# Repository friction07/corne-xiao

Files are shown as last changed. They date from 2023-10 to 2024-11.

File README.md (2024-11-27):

# corne-xiao

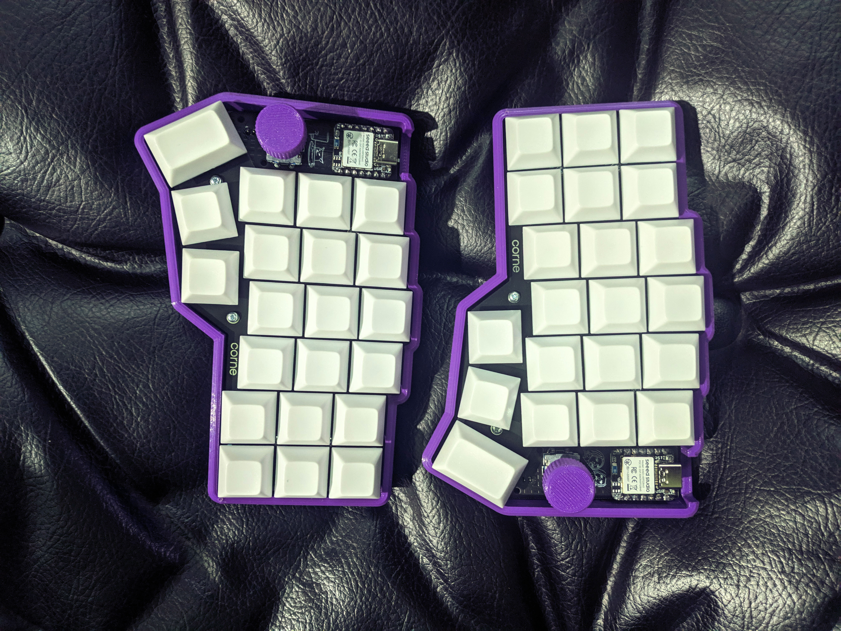
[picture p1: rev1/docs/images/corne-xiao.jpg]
corne-xiao


This is a modified version of the corne keyboard by foostan. It is wireless and uses zmk firmware.
- uses [Seeed Studio XIAO nRF52840](https://www.seeedstudio.com/Seeed-XIAO-BLE-nRF52840-p-5201.html) 
- supports rotary encoder on each half
- supports nice!view
- has a power button and JST header for the battery
- pcb has teardrops

*You can place either an oled or an encoder due to limited space*

***

### rev2
Reversible and breakable(5/6 column) pcb based on corne v2 (north facing).

### rev1 
Non reversible pcb based on corne v3 (south facing). 

***

### Refrences
Thanks to all these project which have been a huge help to me
 
- foostan's [crkbd](https://github.com/foostan/crkbd) 
- GEIST's [KLOR](https://github.com/GEIGEIGEIST/KLOR) and [TOTEM](https://github.com/GEIGEIGEIST/TOTEM)
- Jon Muller's [corne-choc-xiao](https://github.com/JonMuller/gerbers/tree/main/corne-choc-xiao)

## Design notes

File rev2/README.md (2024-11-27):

# CORNE-XIAO

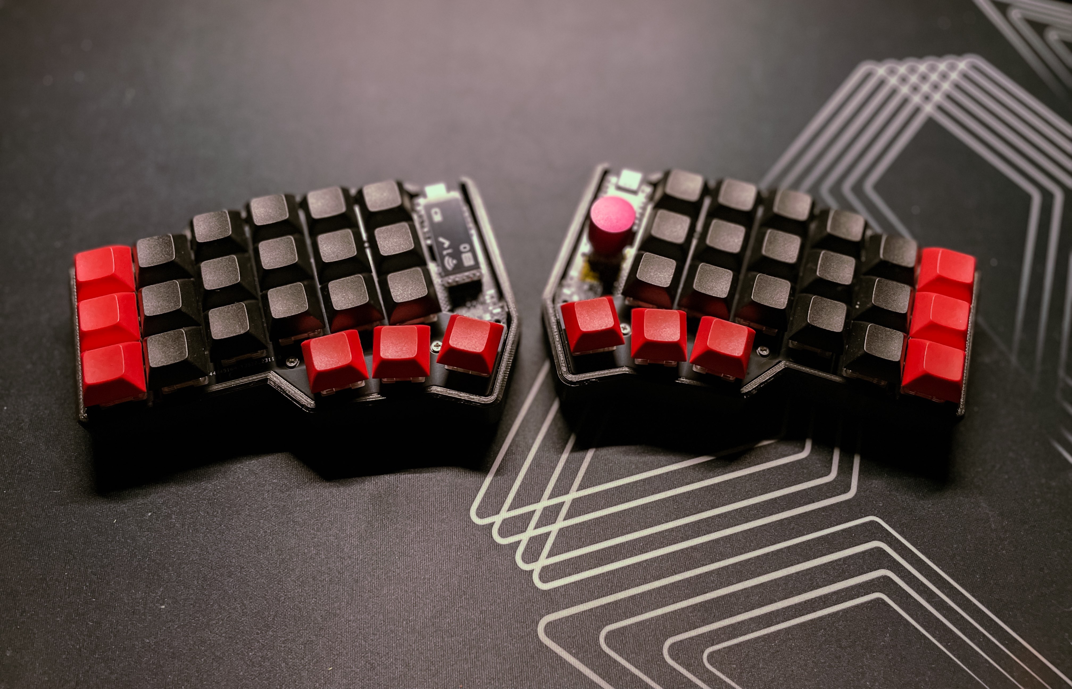
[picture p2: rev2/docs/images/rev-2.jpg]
corne-xiao


***

### Pcb 

[Here](/rev2/PCB) you can find the Gerbers for the corne-xiao. 

***

### Case and Switch-plate

The pcb has the same dimensions and mounting points of the corne-cherry by foostan. So it will work with all the corne cases with the following constraint : **Since the controller is mounted facing up and is different from pro micro, make sure the case has clearance for the usb port**.

_Corne v4 plates/cases will not fit as it has different spacing from the previous versions._

I have also shared files for a case that I personally use [here](/case).

***

### Build Guide

While the build process is similar to most of the keyboards, you can refer to the [build guide](/rev2/docs/buildguide.md) to solder jumpers and other extra stuff.

***

### Firmware

You can find the zmk-config [here](https://github.com/friction07/zmk-config-corne-xiao). ZMK Studio support is enabled by default. Ensure you flash the v1 firmware for the Rev1 PCB and the v2 firmware for the Rev2 PCB.

By default, the firmware uses a [zmk-rgbled-widget](https://github.com/caksoylar/zmk-rgbled-widget) made by [caksoylar](https://github.com/caksoylar) to help with the bluetooth profile and battery status. In case you don't want to use the widget, you can remove the keyword `rgbled_adapter` from `build.yaml`.

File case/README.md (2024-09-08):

# corne-xiao-cases

### corne case by void

Modifed verions of corne cases by void. STL files are shared on [printables](https://www.printables.com/model/1000285-void-case-without-bridge-over-the-usb-port/files)

### chieftain-42

Modified version of the corne chieftain-42 case by ryanmyang found [here](https://github.com/ryanmyang/keyboard-armory/tree/main).

- The case has clearance for the usb port and can fit a battery of upto 4mm thickness with 8mm M2 spacers.

- It is suitable for both rev1/rev2 pcb.

- It will work with both corne v3 and v2 plates (both of them have the same dimensions).

case

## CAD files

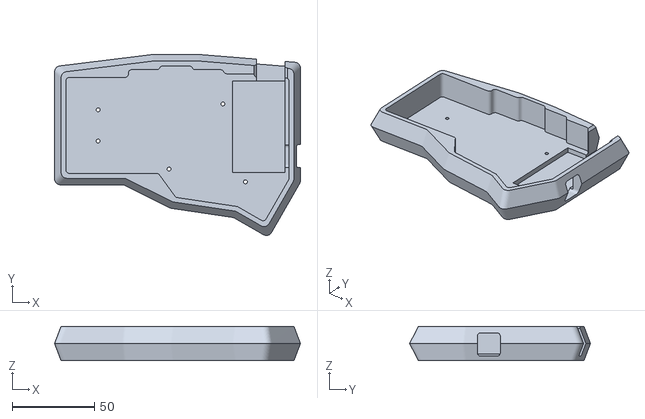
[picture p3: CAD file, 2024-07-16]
case/Corne_xiao_chieftain_left.stl
149.9 x 110.3 x 21.0

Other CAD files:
case/Corne_xiao_chieftain_right.stl

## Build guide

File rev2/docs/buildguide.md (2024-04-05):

# BUILD GUIDE

### List of parts

| Part name | Count | Remarks | 
| :--- | :---: | :--- |
| Seeed Studio XIAO nRF52840  | 02 | https://www.seeedstudio.com/Seeed-XIAO-BLE-nRF52840-p-5201.html |
| Hotswap socket | 42 | Hotswap sockets for MX-style |
| Diodes 1N4148W | 44 | Surface mount diodes in SOD123 package |
| EC11 encoder | 02 | 20 steps, 20 detent Bourns encoder are recommended. You can read more about it here [(Quadrature) Encoders](https://kbd.news/Designing-for-Wireless-1784.html)|
| OLED | 02 | [Nice!view](https://nicekeyboards.com/nice-view) is recommended |
| MCU sockets | 04 | Optional but recommended |
| Power Button | 02 | MSK12C02 SMD Toggle Slide Switch |
| Battery & Battery Connector | 02 | 3.7v lipo battery and S2B-PH-K-S connector |

Note: 
 - Use a battery with a built-in protection circuit.
 - You can directly solder the battery to the large BAT pad (just below the oled connector). If opting for the connector, you'll have to use longer spacers to accommodate them below the pcb.
 - You can solder the power switch on either side of the pcb but I have tested it only on the back side.
 - **This guide assumes you are capable of soldering the diodes, hotswap sockets, power button, encoder and mcu sockets yourself. You can find videos/guides about these stuff very easily. I have only shared some of the extra things you need to take care of.**

**_Shared below are the steps to build the LEFT HALF. Since the pcb is reversible, you can just repeat these but on the opposite side to make a right half._**

### PCB Layout
**Back / Left Side of PCB**

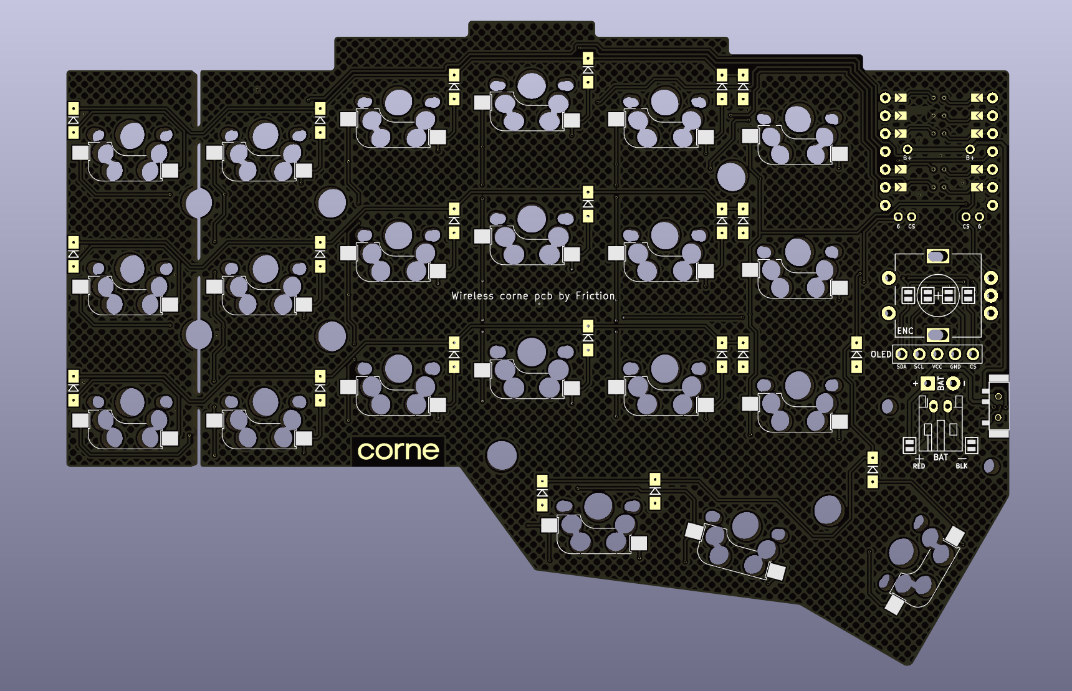
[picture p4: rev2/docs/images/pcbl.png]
Left


**Front / Right Side of PCB**

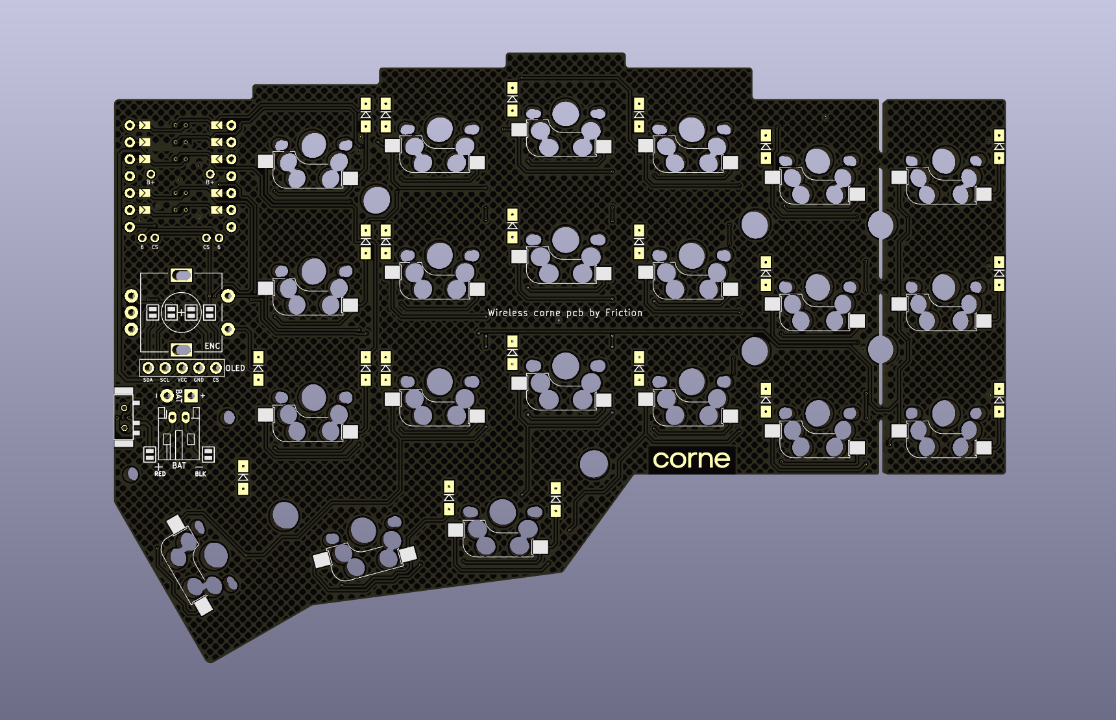
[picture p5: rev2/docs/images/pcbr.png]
Right


***

### Preparing the controller

We have to solder 3 diode legs to the 3 pads at the back of the xiao. The pads being *BAT+* and the two *NFC* pads at the corner. The other battery pad is ignored as it is internally connected to *GND* pin.

> You can skip soldering either/both NFC pads depending on how you are building, since one of the pad is used for 6th col and one for the CS pin of nice!view. These pins have been marked as "6" and "CS" on the PCB for reference.

- **Tin the pads**

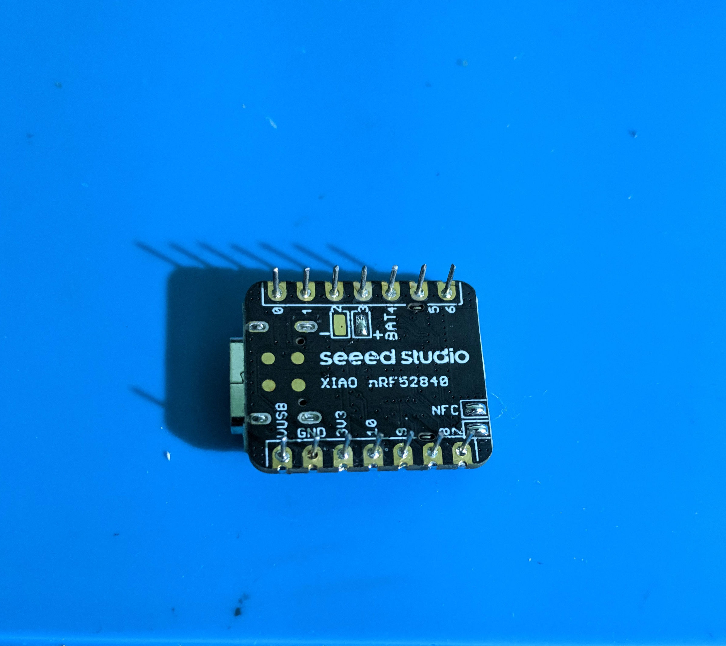
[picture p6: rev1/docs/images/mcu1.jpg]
tin the pads


- **Solder the diode legs**

  You can use wires instead of diode legs. Check under [here](https://github.com/friction07/corne-xiao/blob/main/rev1/docs/buildguide.md#pads-at-the-back).

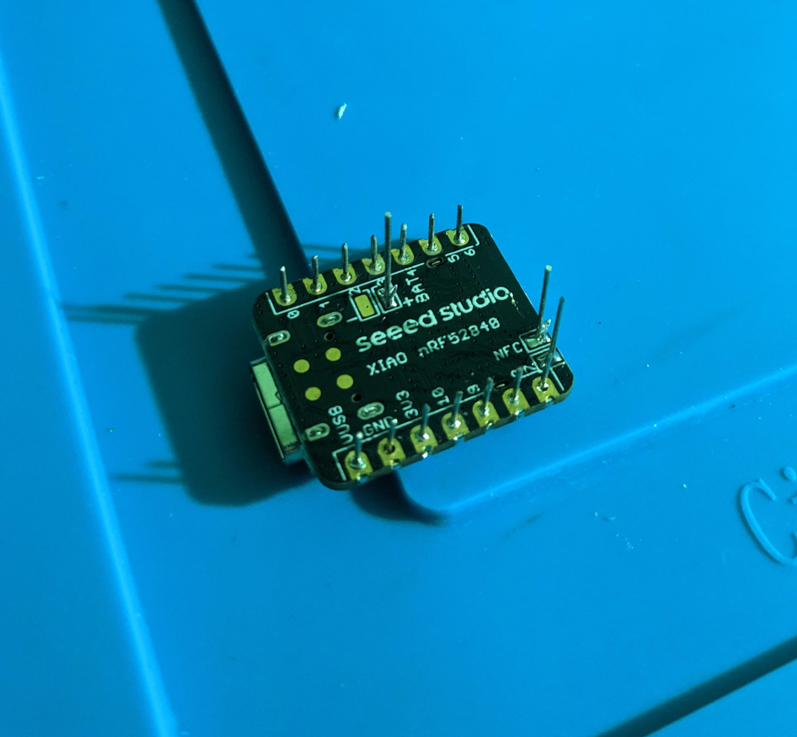
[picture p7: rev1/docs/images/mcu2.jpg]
solder the legs


 **Warning**

> Use low temperature for this (I used 260 C). Hold the legs with help of tweezers. Flux will help a lot. Try to make the legs straight which shouldn't be difficult as they are easy to bend. **Do not overheat or use excess force or you may end up lifting the pads**.
I soldered multiple xiao like this. It looks scary at first but it just needs patience.

### Jumpers

- Bridge jumpers on the opposite side for the xiao-ble that is if the xiao is mounted on the front, bridge the jumpers on the back.
- Bridge jumpers on the same side for battery connector.
- Bridge Jumpers on the same side for oled connector (only if you are using oled instead of encoder).

| Backside of the left half | Bridge the two jumpers for battery connector | Bridge the 10 jumpers for controller(xiao-ble) | Final look after soldering the battery connector and mcu sockets |
| :---: | :---: | :---: | :---: |
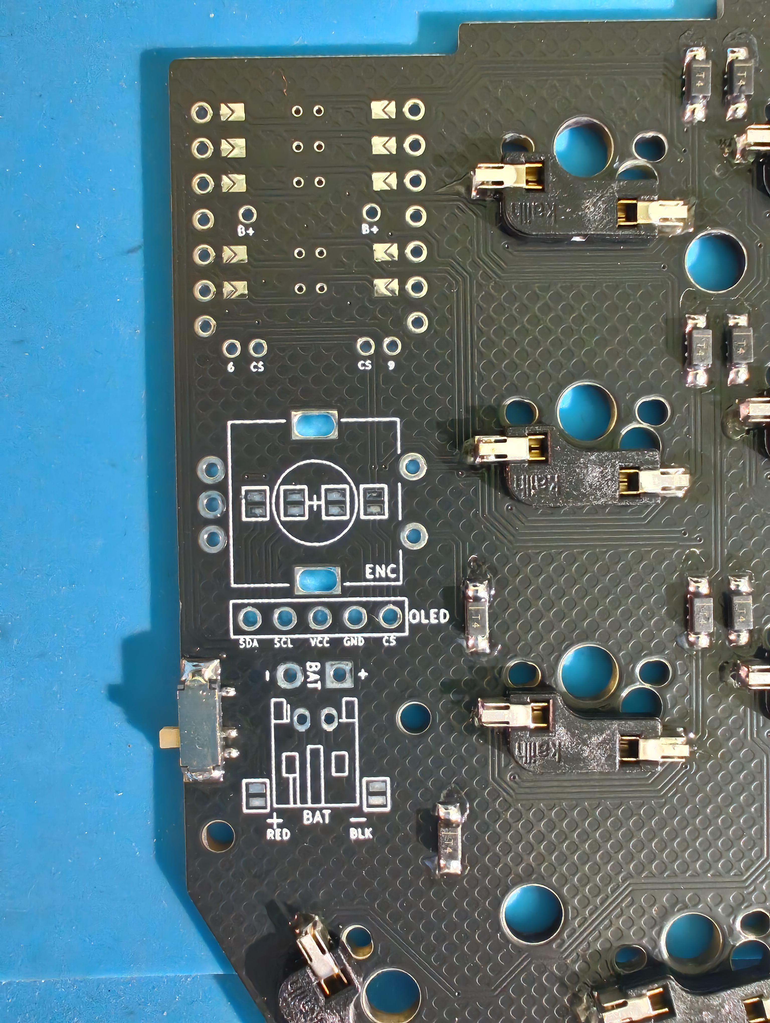
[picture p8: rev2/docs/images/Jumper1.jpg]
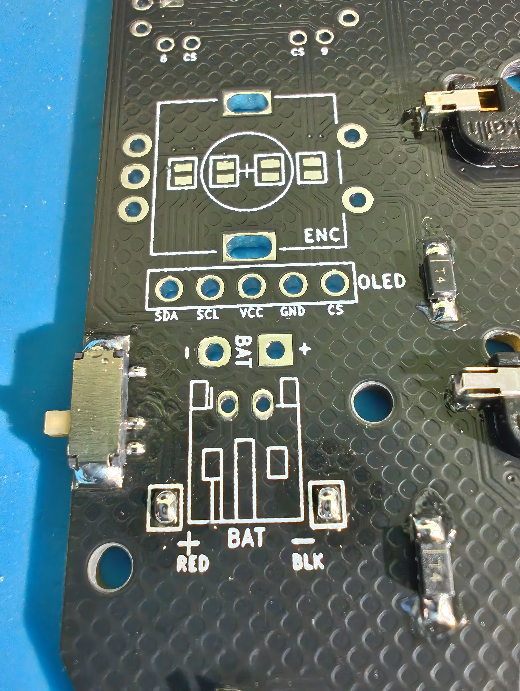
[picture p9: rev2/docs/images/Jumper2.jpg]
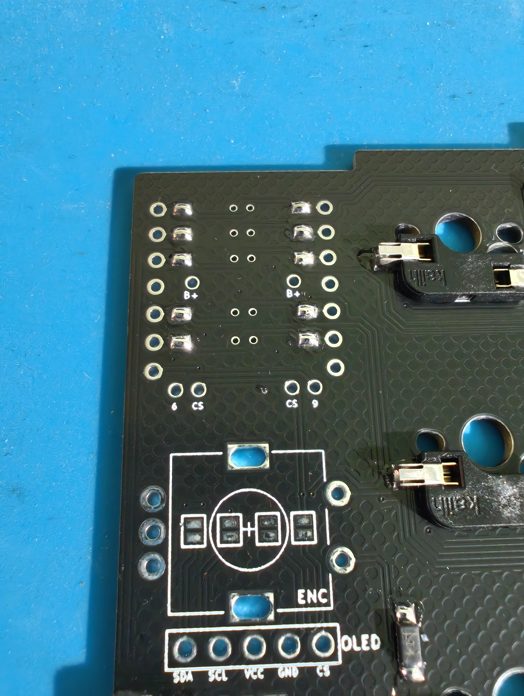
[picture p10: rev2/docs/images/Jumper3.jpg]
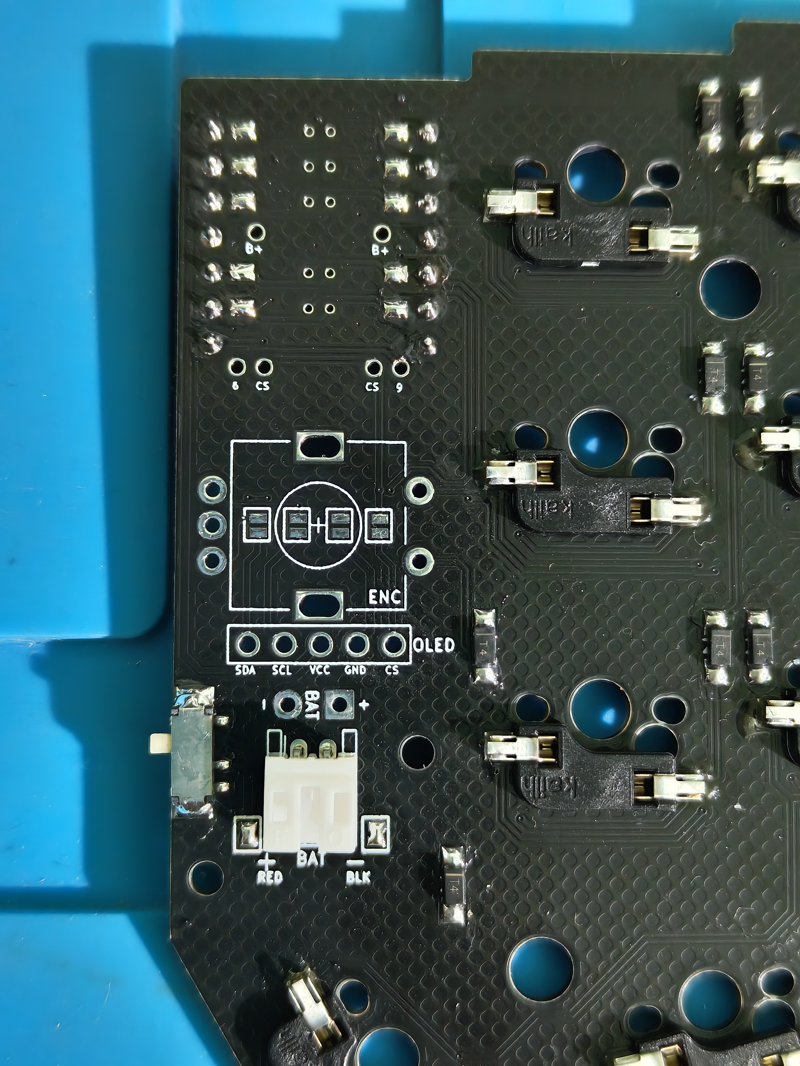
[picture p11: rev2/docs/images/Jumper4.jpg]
|  |  |  |  |

### Solder the controller

- **Push the controller carefully in the pcb**
The image is from rev1 but the process is same for rev2

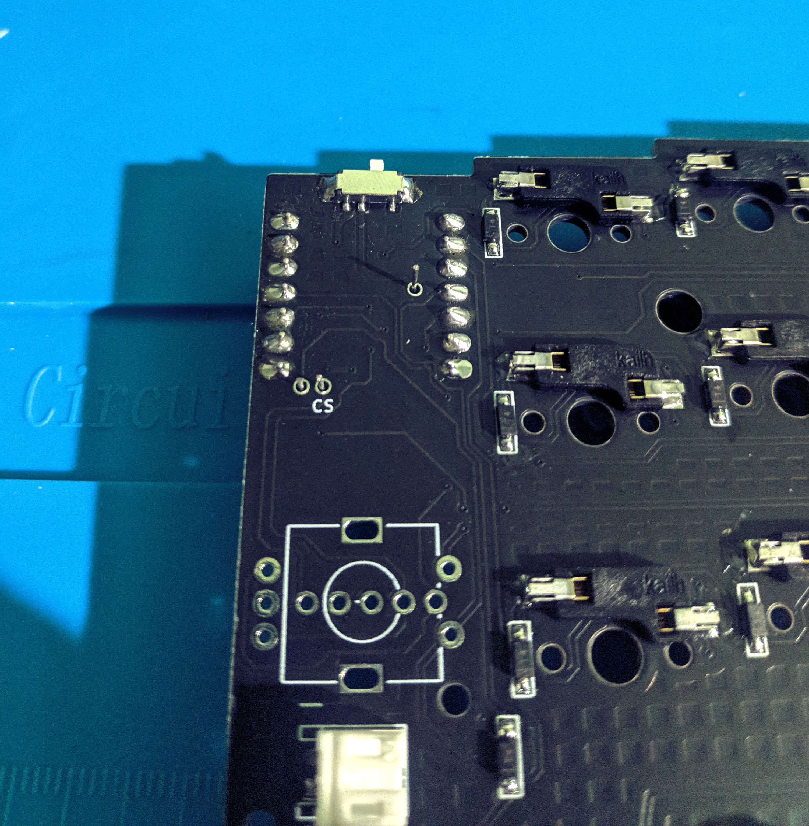
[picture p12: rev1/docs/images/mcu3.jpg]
push it in


- **Solder these legs to the pcb**

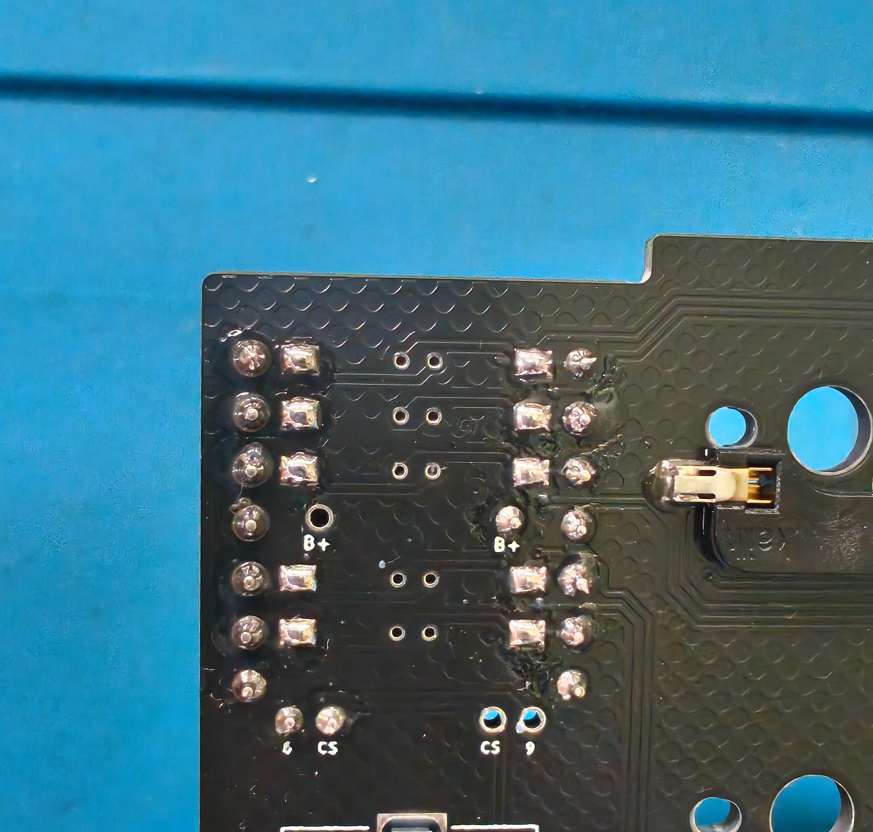
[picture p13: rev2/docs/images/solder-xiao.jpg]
solder the three legs


Yes, this will make the controller non-removable. You can use pogo pins instead but I wasn't able to find them locally, so I went this route.

### Encoder

Before soldering the encoder, make sure the bottom is non-conductive. Since my encoders had a metallic bottom, I used a piece of kapton tape over the jumpers for oled.

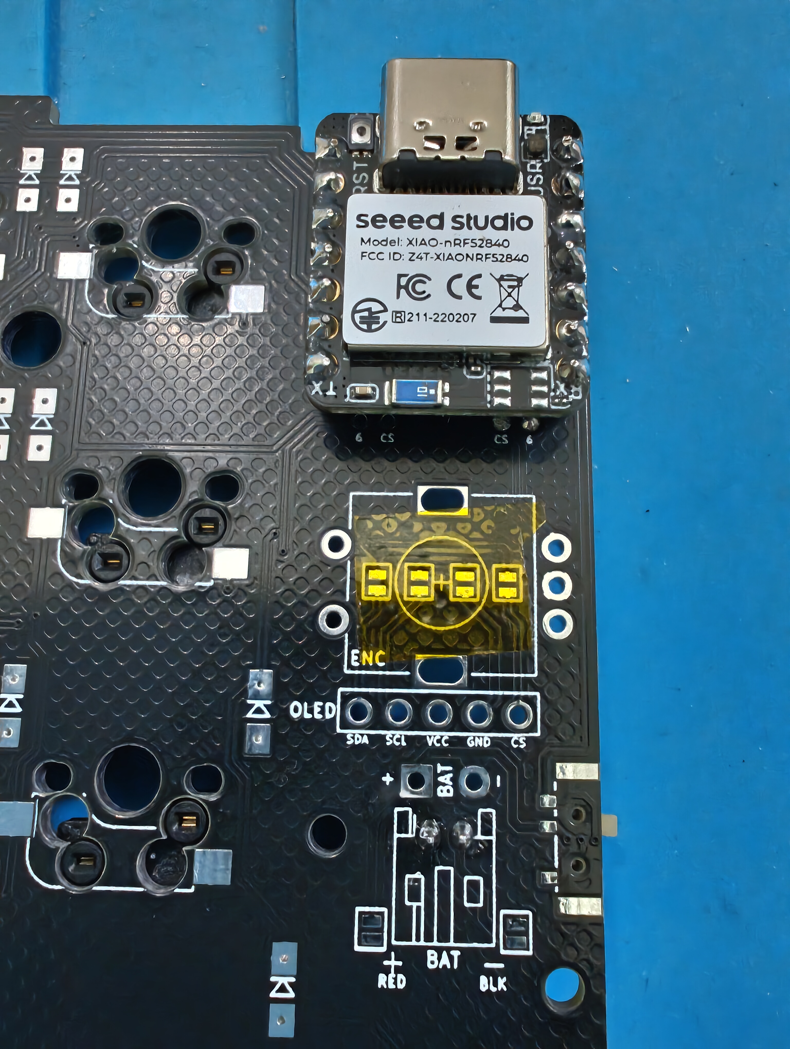
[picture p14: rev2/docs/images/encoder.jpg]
encoder


***

### Final look of the left half

Front
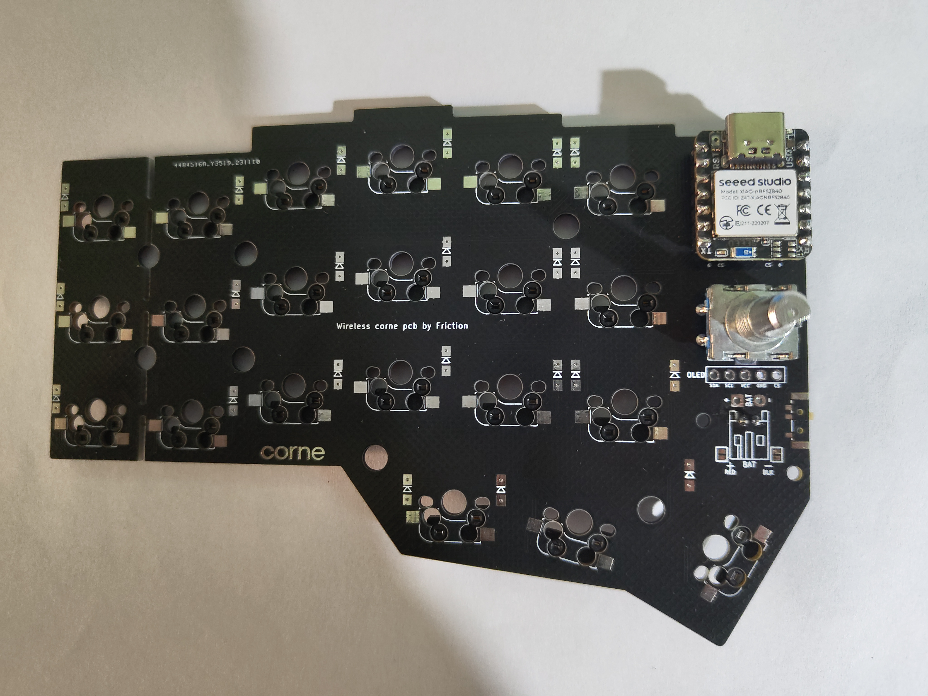
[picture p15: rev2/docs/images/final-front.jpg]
left-half front side

Back
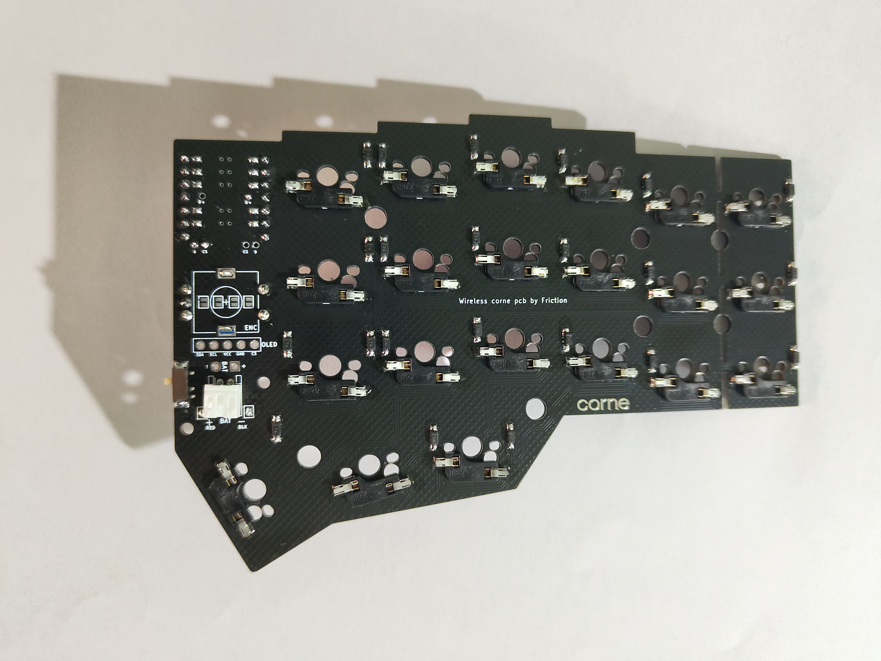
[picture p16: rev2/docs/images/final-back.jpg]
left-half back side


### Both halves together 

Here's how both the halves should look once you are done:

| Front | Back |
| :---: | :---: |
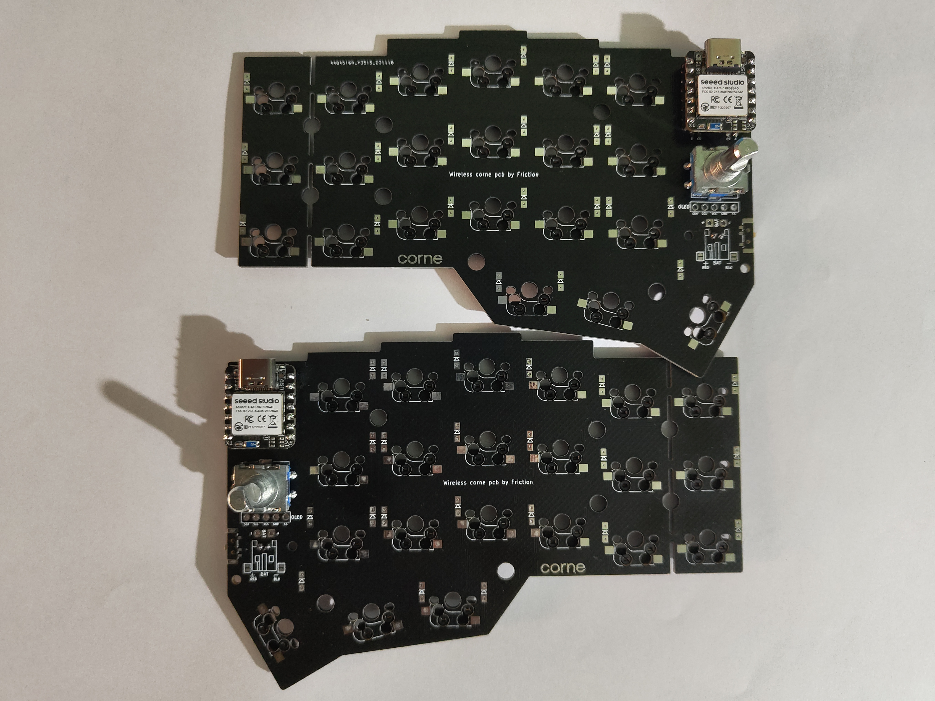
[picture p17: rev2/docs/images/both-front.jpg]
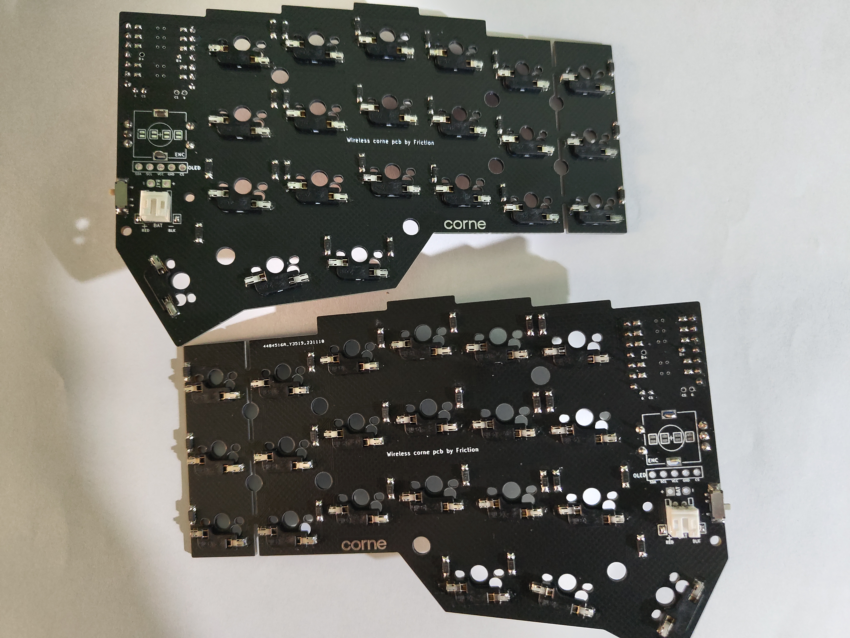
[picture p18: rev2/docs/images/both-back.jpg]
|  |  |

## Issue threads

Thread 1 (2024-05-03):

Compatible Plates & Case

dedisuryadi, 2024-05-03:
So, I've been thinking about building a Corne xiao. But before I take the plunge, I want to ask about the compatible plates and case. The plate should be compatible with this release [corne-cherry-v2.1.0](https://github.com/foostan/crkbd/releases/tag/corne-cherry-v2.1.0), right? Also, do you have any recommendations for a wireless 3D-printed case? Does this case, [Corne Wireless Void Case with better access](https://www.printables.com/model/689497-corne-wireless-void-case-with-better-access), look okay to you in terms of compatibility? Really cool project; I very much appreciate what you've done here. Thank you!

viktorvasylen, 2024-05-03:
Hi there,
I've built my Corne xiao with these [case](https://www.printables.com/de/model/347524-corne-keyboard-case-5-and-6-columns), a variant with 600mah batteries.
I mounted on-off switches in TRRS holes. It is not that attractive but it works just fine for me.

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

dedisuryadi, 2024-05-03:
The battery, red cables and on/off switch make it looks like will not pass airport checkpoint security, love it. Thank you for the links, I will make one.

friction07, 2024-05-16:
I shared files for the case I personally use @dedisuryadi.

dedisuryadi, 2024-06-03:
> I shared files for the case I personally use @dedisuryadi.

Thank you. I already build one using void 600 mah stl, only problem with that case is I need to push the mcu a little bit when plugging a cable, a detachable magnetic cable should solve it.

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

viktorvasylen, 2024-06-03:
@dedisuryadi I have used a file to remove excess material and make the hole bigger

dedisuryadi, 2024-06-03:
@viktorvasylen Yes, thank you. Less work than cut it open completely

Closed 2024-05-04.

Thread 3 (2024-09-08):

3d Files

The-Kriz, 2024-09-08:
Can you provide the KiCad library or a fully assembled STEP file of the PCB?
So I can make case designs

friction07, 2024-09-08:
You can add 3d models to the pcb and export a STEP file from KiCad.

Closed 2024-09-08.

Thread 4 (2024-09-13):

More infos

k0mpreni, 2024-09-13:
Hey, love the project and will order some pcb for it.

I have a few questions:
- Do you maybe have pictures of where and how the battery is soldered?
- Do you recommend any battery capacity?
- Is it compatible with low profile Choc keys?

Thanks!

friction07, 2024-09-17:
Hi, I am glad this project was helpful.

- I have placed the battery underneath the PCB. I use the modified chieftain case which has a cavity of 55x31mm and you can fit a 4mm thick battery within these dimensions  ( STL files are available in the "case" folder ). The size of the battery will depend on the case you use. Check out the "Compatible Plate & Case" issue which has some pictures for reference.

- You should be fine with anything over 100mah. I personally use 400mah batteries.

- It's not compatible with choc keycaps.

k0mpreni, 2024-09-17:
Awesome thanks for the infos!

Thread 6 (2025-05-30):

Nice!view SPI / I2C

JustCryen, 2025-05-30:
Hi I am trying to build a corne xiao based on your config and I have noticed that the OLED connections on board are made for an I2C display and nice!viev display is using SPI.

The guide under List of parts section mentioned that nice!view is recommended, but how can it be if it uses a different communication protocol?

So anyway, are my conclusions correct?
What firmware modifications are necessary to use a nice!view display?

dieselsaurav, 2025-06-06:
Facing the same issue. @friction07 please help

JustCryen, 2025-06-07:
Interesting, so even though the xiao has a clear SPI and I²C pin assignment, you're saying that they can be used interchangeably?
For now I am handwireing this build anyway, so I can connect the "correct" pins but if I understood you correctly, this is really interesting.

I have been using ZMK for a while now, but I never had to dig into the board config quite as much.  So this is still kind of new to me.

I'll report back if I have any more questions, thanks!

Closed 2025-06-14.

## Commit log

2024-01-27 revision 2
    [mx-corne-xiao.kicad_sch]
2024-01-27 remove pcb backups and fix docs
2024-04-10 updated plate/case information
2024-07-16 reorganized firmware
    [Corne_xiao_chieftain_left.stl, Corne_xiao_chieftain_right.stl]
2024-09-08 added more options for case
2024-09-09 added teardrops and increased via diameter to match some vendor's capabilites
    [corne-xiao.kicad_sch, mx-corne-xiao.kicad_sch]
